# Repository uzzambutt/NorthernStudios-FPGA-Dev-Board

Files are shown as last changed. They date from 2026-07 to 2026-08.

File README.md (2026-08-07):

# NorthernStudios FPGA Dev Board





**Designed by Muhammad Uzzam Butt // Made for Macondo**

---

## Overview
This FPGA Devboard is designed in KiCad v9.0 and is built around the Gowin GW1NSR-4C, a hybrid FPGA chip containing an embedded ARM Cortex-M3 microcontroller. 

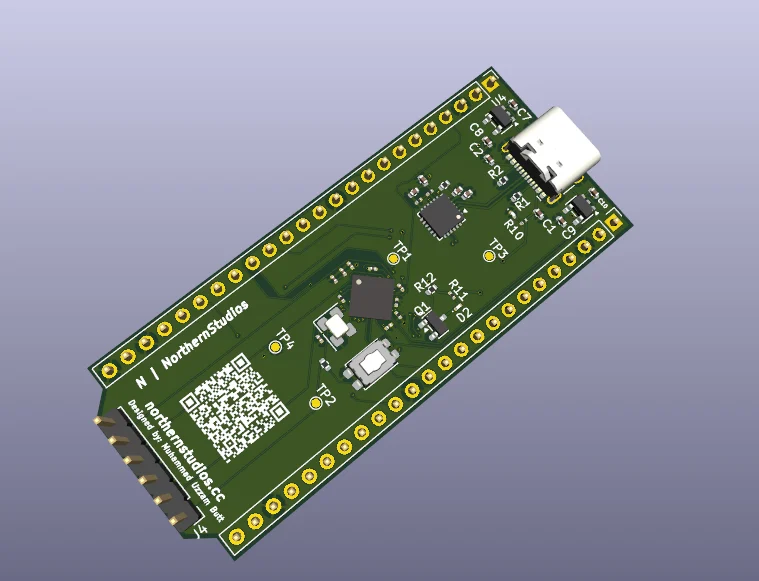
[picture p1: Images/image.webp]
NorthernStudios FPGA Dev Board Thumbnail


---

## Hardware Specifications

### FPGA Core
* FPGA Chip: Gowin GW1NSR-4C (specifically GW1NSR-4C_MG64P in an MBGA64 package)
* Embedded ARM Cortex-M3 hard core processor
* 4,608 Look Up Tables (LUTs)
* 3,456 Flip Flops (FFs)
* Embedded block SRAM and internal Flash memory

### Power Delivery
* Input Source: USB Type-C (+5V VBUS)
* Core Regulator: AP2112K 1.2 LDO (600mA) generating +1.2V for the FPGA core
* I/O and Peripheral Regulator: AP2112K-3.3 LDO (600mA) generating +3.3V for I/O banks, clocking, and UART bridge
* Decoupling: Optimized bypass capacitor networks (0.1uF and 10uF) on each power pin to ensure low-noise rails

### Interfaces and Connectivity
* USB Connector: USB 2.0 Type-C interface
* Serial Communication: CP2102N USB-to-UART bridge for programming and debug output
* Main Breakout: Dual 24-pin headers for breadboard compatibility, exposing FPGA I/Os, system power, and ground pins
* Accessory Port: 6-pin PMOD style header for SPI, I2C, or UART hardware attachments

### Clocking and User Controls
* Clock Oscillator: SG-8002CE (24.0000 MHz) active crystal oscillator
* User Controls: Push buttons for system reset and user input
* Visual Indicators: Status and user-configurable LEDs
* Level Translation: BSS138 N-channel MOSFET circuit for voltage-level switching

---

## Bill of Materials (BOM)

A complete list of components required to assemble the dev board is detailed in the table below (sourced from [bom.csv](file:///D:/NS%20FPGA/hardware/jlcpcb/production_files/bom.csv)):

| Comment | Designator | Footprint | LCSC | Quantity |
| :--- | :--- | :--- | :--- | :--- |
| 0.1uF | C1, C4, C6 | C_0402_1005Metric | C141382 | 3 |
| 0.1uF | C11, C12, C13, C14, C15, C16, C17 | C_0201_0603Metric | C66938 | 7 |
| 10k | R12, R3, R9 | R_0402_1005Metric | C25725 | 3 |
| 10uF | C10, C7, C8, C9 | C_0402_1005Metric | C15525 | 4 |
| 1k | R10 | R_0201_0603Metric | C131396 | 1 |
| 22.1k | R4 | R_0201_0603Metric | C423662 | 1 |
| 330 | R11 | R_0201_0603Metric | C274872 | 1 |
| 4.7k | R7, R8 | R_0201_0603Metric | C142008 | 2 |
| 4.7uF | C2, C3, C5 | C_0402_1005Metric | C23733 | 3 |
| 47.5k | R5 | R_0201_0603Metric | C166179 | 1 |
| 5.1k | R1, R2 | R_0402_1005Metric | C25905 | 2 |
| AP2112K-1.2 | U4 | SOT-23-5 | C49451994 | 1 |
| AP2112K-3.3 | U3 | SOT-23-5 | C3021085 | 1 |
| BSS138 | Q1 | SOT-23 | C52895 | 1 |
| CP2102N-Axx-xQFN24 | U2 | QFN-24-1EP_4x4mm_P0.5mm_EP2.6x2.6mm | C969151 | 1 |
| LED | D1, D2 | LED_0201_0603Metric | C3646922 | 2 |
| R22 | R6 | R_0201_0603Metric | C142011 | 1 |
| SG-8002CE(24.0000M) | Y1 | Oscillator_SMD_SeikoEpson_SG8002CE-4Pin_3.2x2.5mm | C390322 | 1 |
| SW_Push | SW1 | SW_SPST_EVQP2_ShortPushTravel_H2.1mm | C2915174 | 1 |
| USB_C_Receptacle_USB2.0_14P | J1 | USB_C_Receptacle_HCTL_HC-TYPE-C-16P-01A | C165948 | 1 |
| GW1NSR-4C-MG64P | U1 | BGA-64_8x8_4.2x4.2mm | Gowin GW1NSR-4C-MG64P | 1 |
| TestPoint | TP4 | TestPoint_Pad_D1.0mm | | 1 |
| TestPoint | TP3 | TestPoint_Pad_D1.0mm | | 1 |
| TestPoint | TP2 | TestPoint_Pad_D1.0mm | | 1 |
| TestPoint | TP1 | TestPoint_Pad_D1.0mm | | 1 |
| Jtag PIN | J4 | PinHeader_1x06_P2.54mm_Vertical | | 1 |
| Conn_01x24_Pin | J3 | PinHeader_1x24_P2.54mm_Vertical | | 1 |
| Conn_01x24_Pin | J2 | PinHeader_1x24_P2.54mm_Vertical | | 1 |

---

## KiCad Setup

1. Open the project using KiCad v9.0 or later by selecting [NS FPGA.kicad_pro](file:///D:/NS%20FPGA/hardware/NS%20FPGA.kicad_pro).
2. The Gowin FPGA symbol is located in the local library file [gowin_fpga.lib](file:///D:/NS%20FPGA/gowin_fpga.lib). Make sure it is mapped correctly in your KiCad symbol library table if you plan to edit the schematics.

---

## License

This project is open-source hardware licensed under the [MIT License](LICENSE).

---

*Designed by Muhammad Uzzam Butt // Made for Macondo*

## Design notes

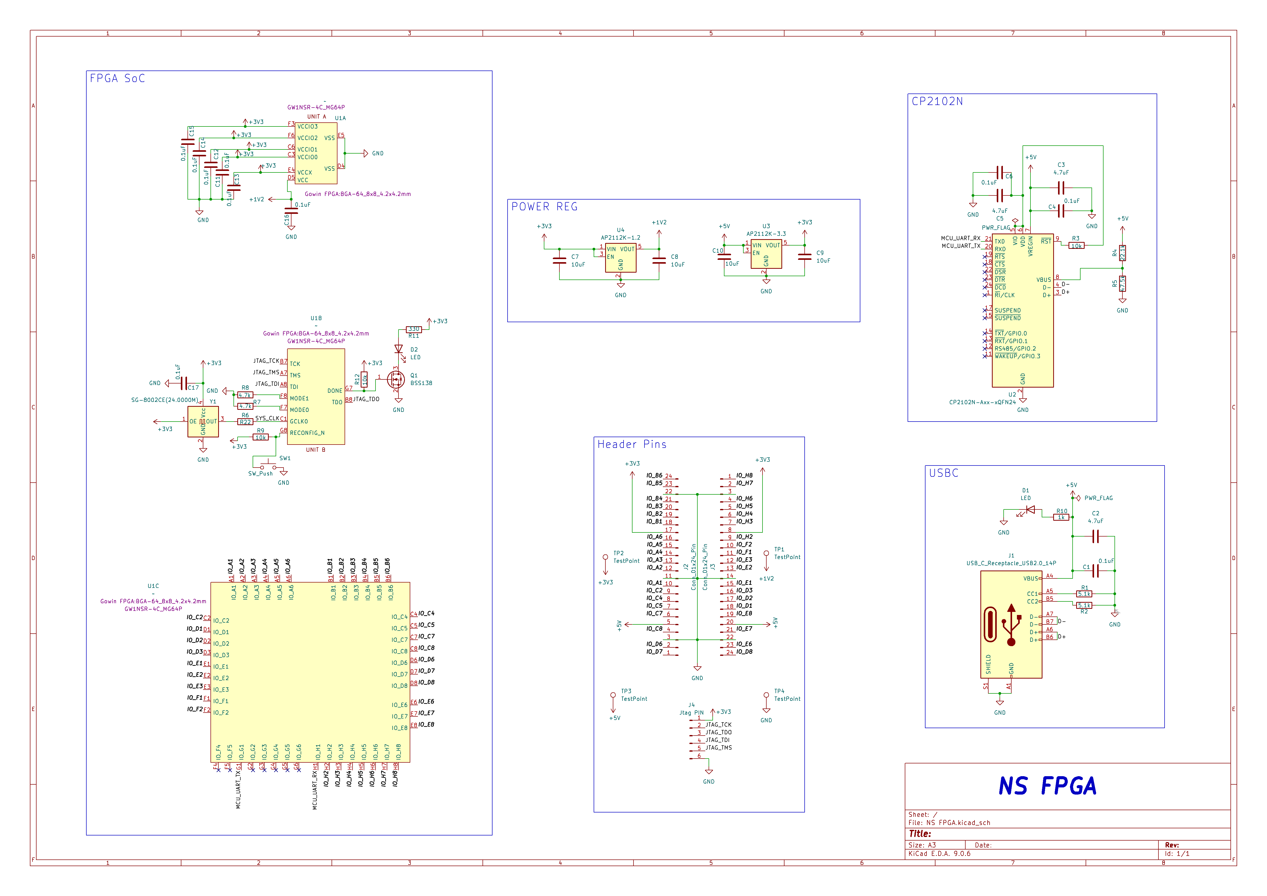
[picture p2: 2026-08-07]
Images/image.png

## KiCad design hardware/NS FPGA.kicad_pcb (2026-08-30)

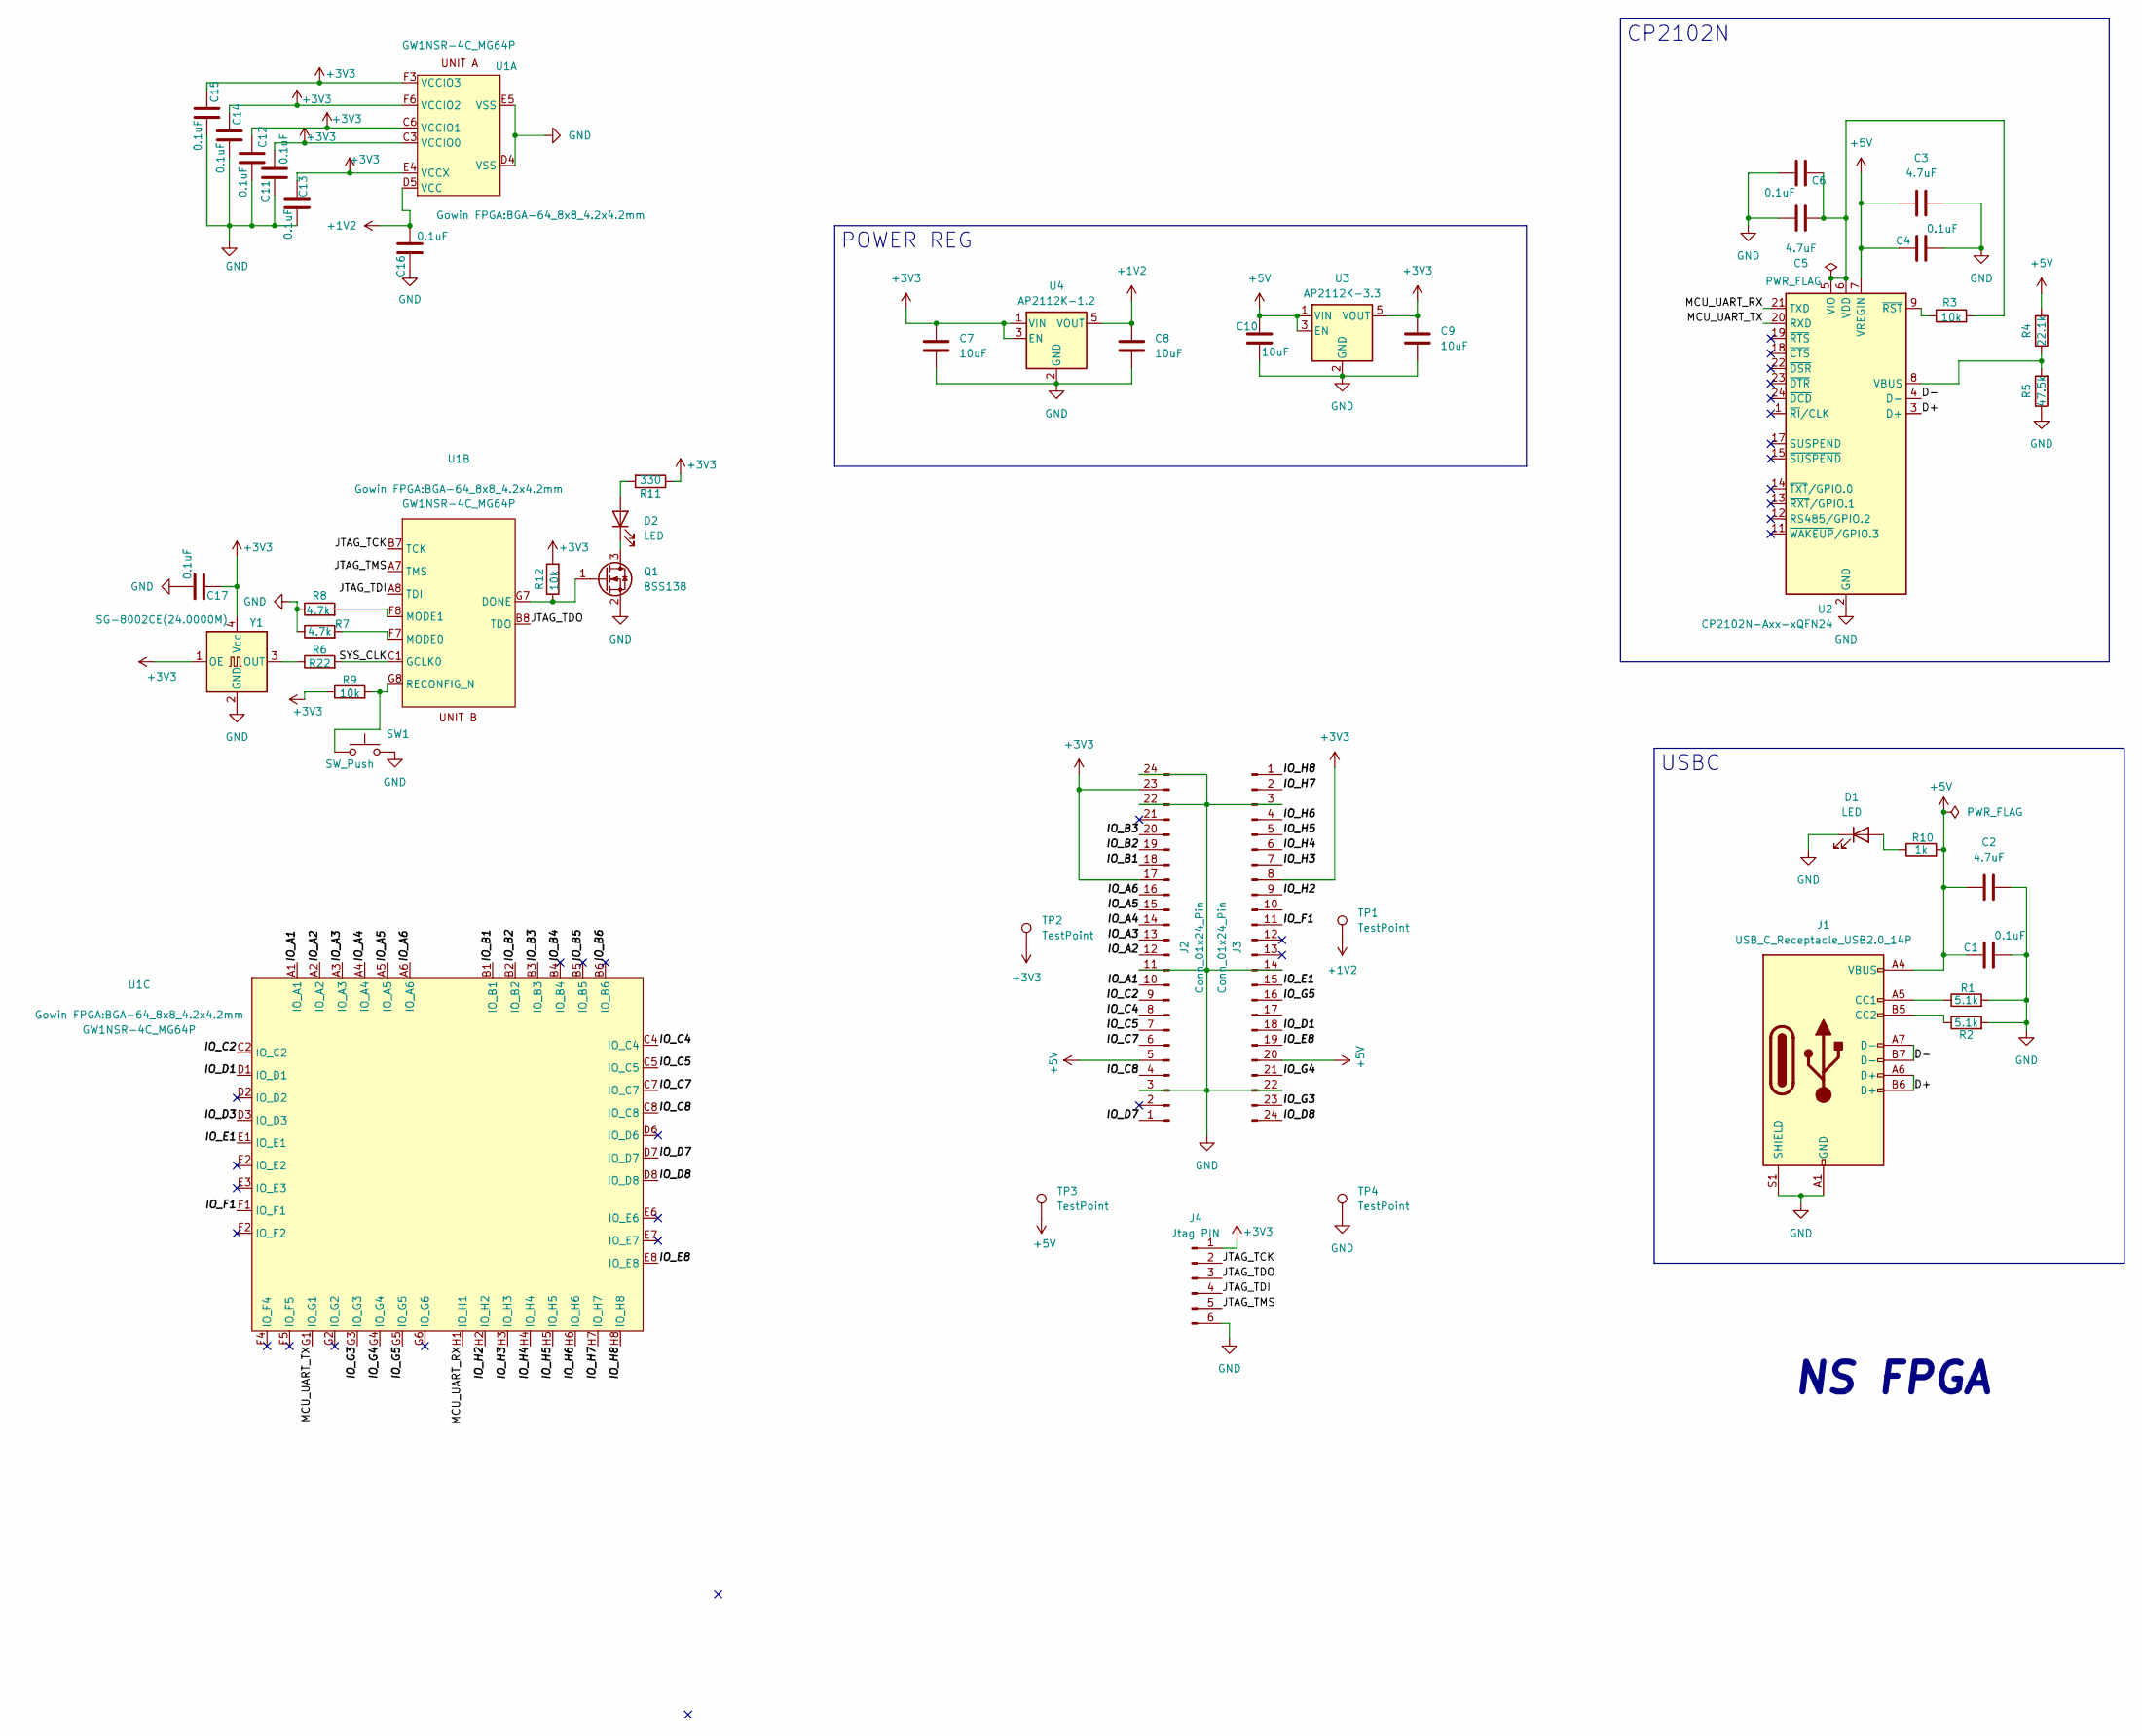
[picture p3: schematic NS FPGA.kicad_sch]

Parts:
C1, C4, C6: 0.1uF; C_0402_1005Metric
C2, C3, C5: 4.7uF; C_0402_1005Metric
C7, C8, C9, C10: 10uF; C_0402_1005Metric
C11, C12, C13, C14, C15, C16, C17: 0.1uF; C_0201_0603Metric
D1, D2: LED; LED_0201_0603Metric
J1: USB_C_Receptacle_USB2.0_14P; USB_C_Receptacle_HCTL_HC-TYPE-C-16P-01A
J2, J3: Conn_01x24_Pin; PinHeader_1x24_P2.54mm_Vertical
J4: Jtag PIN; PinHeader_1x06_P2.54mm_Vertical
Q1: BSS138; SOT-23
R1, R2: 5.1k; R_0402_1005Metric
R3, R9, R12: 10k; R_0402_1005Metric
R4: 22.1k; R_0201_0603Metric
R5: 47.5k; R_0201_0603Metric
R6: R22; R_0201_0603Metric
R7, R8: 4.7k; R_0201_0603Metric
R10: 1k; R_0201_0603Metric
R11: 330; R_0201_0603Metric
SW1: SW_Push; SW_SPST_EVQP2_ShortPushTravel_H2.1mm
TP1, TP2, TP3, TP4: TestPoint; TestPoint_Pad_D1.0mm
U1: BGA-64_8x8_4.2x4.2mm
U2: CP2102N-Axx-xQFN24; QFN-24-1EP_4x4mm_P0.5mm_EP2.6x2.6mm
U3: AP2112K-3.3; SOT-23-5
U4: AP2112K-1.2; SOT-23-5
Y1: SG-8002CE(24.0000M); Oscillator_SMD_SeikoEpson_SG8002CE-4Pin_3.2x2.5mm

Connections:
+1V2: C8.1, C16.2, TP1.1, U1.D5 (VCC), U4.5 (VOUT)
+3V3: C7.1, C9.1, C11.2, C12.1, C13.1, C14.1, C15.1, C17.1, J2.17, J2.23, J3.8, J4.1, R9.1, R11.1, R12.2, TP2.1, U1.C3 (VCCIO0), U1.C6 (VCCIO1), U1.E4 (VCCX), U1.F3 (VCCIO3), U1.F6 (VCCIO2), U3.5 (VOUT), U4.1 (VIN), U4.3 (EN), Y1.1 (OE), Y1.4 (Vcc)
+5V: C1.1, C2.1, C3.1, C4.1, C10.1, J1.A4 (VBUS), J1.A9 (VBUS), J1.B4 (VBUS), J1.B9 (VBUS), J2.5, J3.20, R4.2, R10.2, TP3.1, U2.7 (VREGIN), U3.1 (VIN), U3.3 (EN)
/D+: J1.A6 (D+), J1.B6 (D+), U2.3 (D+)
/D-: J1.A7 (D-), J1.B7 (D-), U2.4 (D-)
/IO_A1: J2.10, U1.A1 (IO_A1)
/IO_A2: J2.12, U1.A2 (IO_A2)
/IO_A3: J2.13, U1.A3 (IO_A3)
/IO_A4: J2.14, U1.A4 (IO_A4)
/IO_A5: J2.15, U1.A5 (IO_A5)
/IO_A6: J2.16, U1.A6 (IO_A6)
/IO_B1: J2.18, U1.B1 (IO_B1)
/IO_B2: J2.19, U1.B2 (IO_B2)
/IO_B3: J2.20, U1.B3 (IO_B3)
/IO_B4: U1.B4 (IO_B4)
/IO_B5: U1.B5 (IO_B5)
/IO_B6: U1.B6 (IO_B6)
/IO_C2: J2.9, U1.C2 (IO_C2)
/IO_C4: J2.8, U1.C4 (IO_C4)
/IO_C5: J2.7, U1.C5 (IO_C5)
/IO_C7: J2.6, U1.C7 (IO_C7)
/IO_C8: J2.4, U1.C8 (IO_C8)
/IO_D1: J3.18, U1.D1 (IO_D1)
/IO_D3: U1.D3 (IO_D3)
/IO_D7: J2.1, U1.D7 (IO_D7)
/IO_D8: J3.24, U1.D8 (IO_D8)
/IO_E1: J3.15, U1.E1 (IO_E1)
/IO_E8: J3.19, U1.E8 (IO_E8)
/IO_F1: J3.11, U1.F1 (IO_F1)
/IO_G3: J3.23, U1.G3 (IO_G3)
/IO_G4: J3.21, U1.G4 (IO_G4)
/IO_G5: J3.16, U1.G5 (IO_G5)
/IO_H2: J3.9, U1.H2 (IO_H2)
/IO_H3: J3.7, U1.H3 (IO_H3)
/IO_H4: J3.6, U1.H4 (IO_H4)
/IO_H5: J3.5, U1.H5 (IO_H5)
/IO_H6: J3.4, U1.H6 (IO_H6)
/IO_H7: J3.2, U1.H7 (IO_H7)
/IO_H8: J3.1, U1.H8 (IO_H8)
/JTAG_TCK: J4.2, U1.B7 (TCK)
/JTAG_TDI: J4.4, U1.A8 (TDI)
/JTAG_TDO: J4.3, U1.B8 (TDO)
/JTAG_TMS: J4.5, U1.A7 (TMS)
/MCU_UART_RX: U1.H1 (IO_H1), U2.21 (TXD)
/MCU_UART_TX: U1.G1 (IO_G1), U2.20 (RXD)
/SYS_CLK: R6.2, U1.C1 (GCLK0)
GND: C1.2, C2.2, C3.2, C4.2, C5.2, C6.2, C7.2, C8.2, C9.2, C10.2, C11.1, C12.2, C13.2, C14.2, C15.2, C16.1, C17.2, D1.1 (K), J1.A1 (GND), J1.A12 (GND), J1.B1 (GND), J1.B12 (GND), J1.S1 (SHIELD), J2.3, J2.11, J2.22, J2.24, J3.3, J3.14, J3.22, J4.6, Q1.2 (S), R1.2, R2.2, R5.1, R7.1, R8.1, SW1.2, TP4.1, U1.D4 (VSS), U1.E5 (VSS), U2.2 (GND), U2.25 (GND), U3.2 (GND), U4.2 (GND), Y1.2 (GND)
unnamed: D1.2 (A), R10.1
unnamed: D2.2 (A), R11.2
unnamed: D2.1 (K), Q1.3 (D)
unnamed: J1.A5 (CC1), R1.1
unnamed: J1.B5 (CC2), R2.1
unnamed: Q1.1 (G), R12.1, U1.G7 (DONE)
unnamed: R7.2, U1.F7 (MODE0)
unnamed: R8.2, U1.F8 (MODE1)
unnamed: R9.2, SW1.1, U1.G8 (RECONFIG_N)
unnamed: R4.1, R5.2, U2.8 (VBUS)
unnamed: C5.1, C6.1, R3.2, U2.5 (VIO), U2.6 (VDD)
unnamed: R3.1, U2.9 (~RST)
unnamed: R6.1, Y1.3 (OUT)

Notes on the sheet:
NS FPGA
POWER REG
USBC
CP2102N

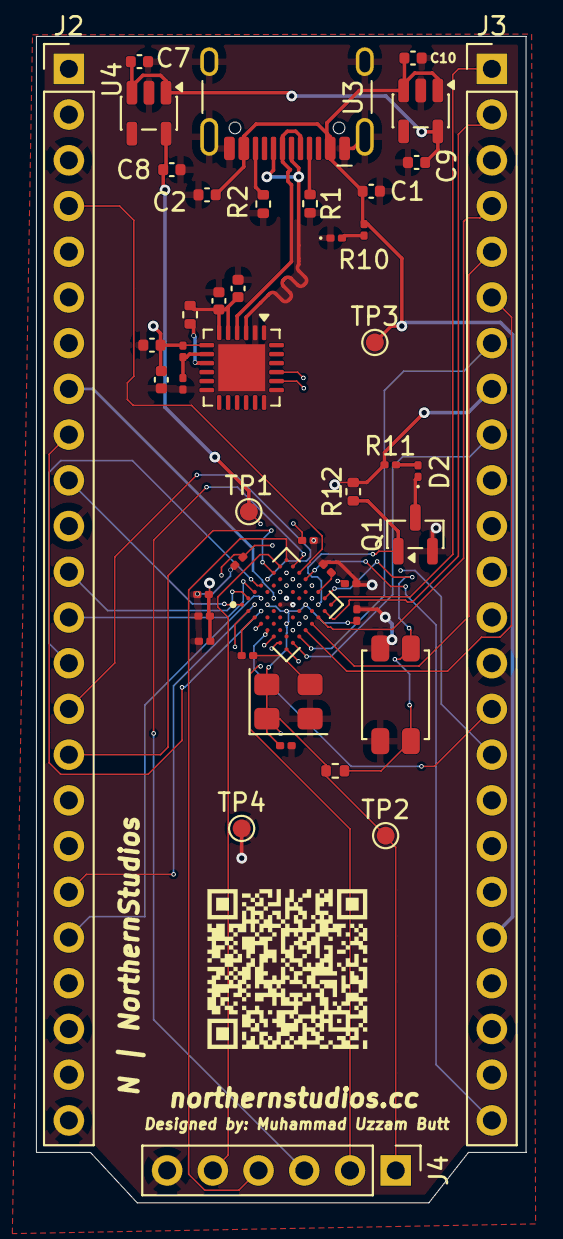
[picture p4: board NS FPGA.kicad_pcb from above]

Board: 6 copper layers, 27.2 x 64.8 mm, 46 parts (0 on the bottom side), 56 nets.

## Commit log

2026-07-13 Initialize project structure and KiCad workspace
    [NS FPGA.kicad_pcb, NS FPGA.kicad_sch]
2026-07-13 Update KiCad schematics and add gowin_fpga symbol library
    [NS FPGA.kicad_sch]
2026-07-13 Update schematic
    [NS FPGA.kicad_sch]
2026-07-14 drawn 80% of the circuit schematic
    [NS FPGA.kicad_sch]
2026-07-14 completed the schematic
    [NS FPGA.kicad_sch]
2026-07-14 routed some of the BGA chip
    [NS FPGA.kicad_pcb, NS FPGA.kicad_sch]
2026-07-14 Complete PCB layout, add documentation image, and update README
    [NS FPGA.kicad_pcb, NS FPGA.kicad_sch]
2026-07-15 added pin numbering silkscreen
    [NS FPGA.kicad_pcb, NS FPGA.kicad_sch]
2026-07-15 created BOM and CPL with LCSC parts
    [BOM-NS FPGA.csv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]
2026-08-07 bom rename
    [bom.csv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]
2026-08-30 1: fixed one of the differential trace by joining it with the other pad with a via. 2: Connected the floating ground pad with a trace to the body of the USB which is connected to the rest of the circ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
    [NS FPGA.kicad_pcb]

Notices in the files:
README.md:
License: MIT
